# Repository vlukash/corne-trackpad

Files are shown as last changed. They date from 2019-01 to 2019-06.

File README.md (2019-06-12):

# Trackpad in a Keycap for Corne/CrKbd Keyboard

This is a Trackpad add-on for the [Corne](https://github.com/foostan/crkbd) keyboard.

This add-on consists of two main parts:
- an adapter PCB that goes between Elite-C and the main keyboard
- a connector PCB that links trackpad with the adapter

There are two different options available for the Trackpad sensor mount (connector PCB)
- on the 'H' button keycap via flex cable (Connector V1)
- no-flex mount directly on the connector PCB (Connector V2)

Both options compatible with the main adapter PCB, see photos below.

Schematics and PCB design included in this repository.
[Trackpad.c](https://github.com/vlukash/qmk_firmware/blob/master/keyboards/crkbd/keymaps/vlukash_trackpad_right/trackpad.c) reads the trackpad data and sends it to QMK.

Please find more information in my [blogpost](https://vlukash.com/2019/01/15/trackpad-in-keycap-corne-crkbd-keyboard/).

## Video
Turn on the subtitles option :)

https://www.youtube.com/watch?v=eY_9cieYMEQ

## Build Guide
https://github.com/vlukash/corne-trackpad/blob/master/build-guide.md

## Firmware
Corne keyboard uses [QMK](https://github.com/qmk/qmk_firmware) - an open-source keyboard firmware project.  
Please use [QMK guide](https://docs.qmk.fm/#/newbs_getting_started) to setup your local environment.  

The Trackpad add-on uses right-master configuration, and USB cable connects to the right keyboard with the trackpad.

Because of the adapter PCB, left and right keyboards have to be flashed with different firmware.

To build and flash the right keyboard (with the trackpad):
```
make crkbd:vlukash_trackpad_right:dfu
```
And the left part
```
make crkbd:vlukash_trackpad_left:dfu
```

[Here is a PR](https://github.com/qmk/qmk_firmware/pull/5925) that could be used as an example for creating your own Corne keymaps with the Trackpad add-on support.

## Photos
Trackpad sensor mounted directly on the connector PCB (Connector V2):
Corne with no-flex trackpad
Trackpad sensor mounted on 'H' button keycap via flex cable (Connector V1):
Corne with trackpad

All parts

Adapter

Adapter

Adapter

Connector

Connector

Connector

Button

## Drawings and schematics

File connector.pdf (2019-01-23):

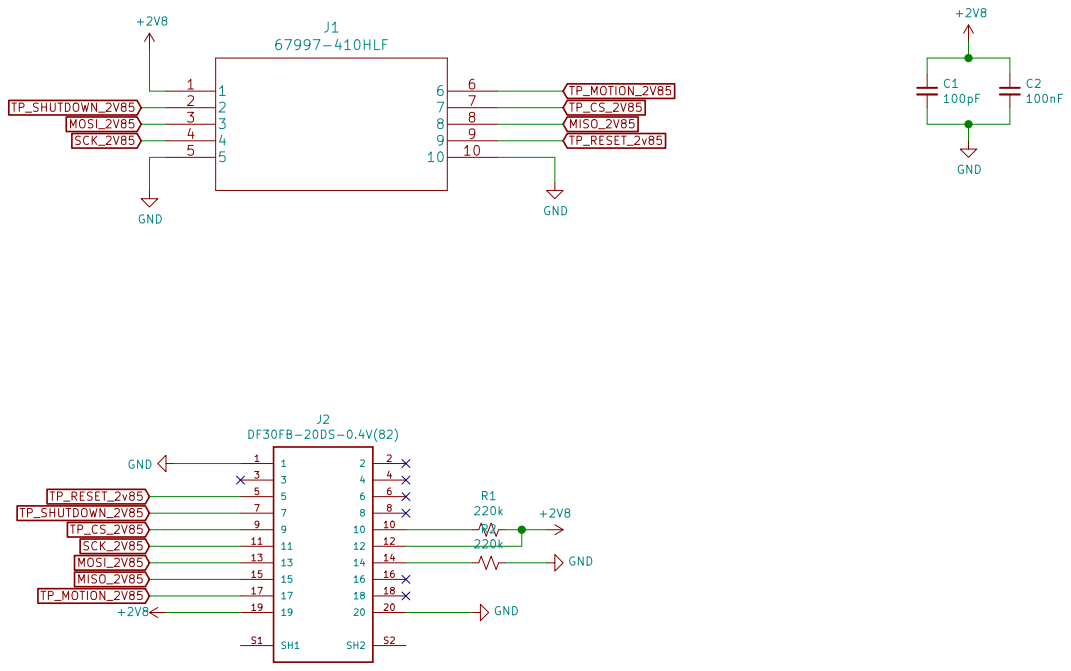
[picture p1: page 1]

File: trackpad_conn.sch Sheet: / vlukash Connector for the BlackBerry 8520 trackpad

Id: 1/1 Title: Trackpad connector

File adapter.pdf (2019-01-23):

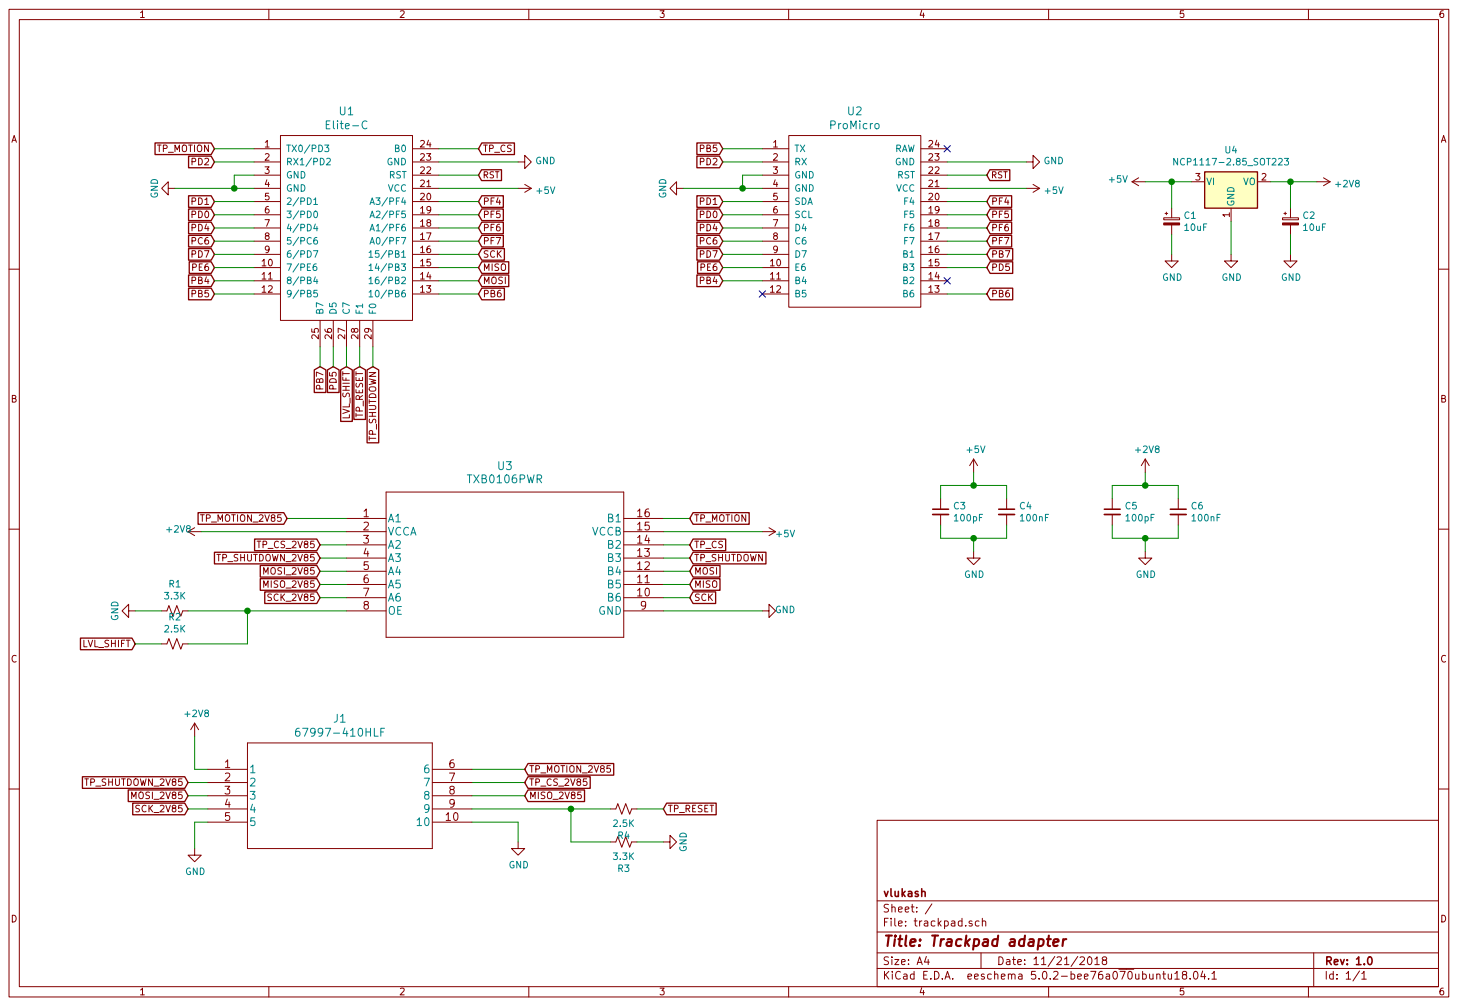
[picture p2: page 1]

File: trackpad.sch Sheet: / vlukash

Id: 1/1 Title: Trackpad adapter

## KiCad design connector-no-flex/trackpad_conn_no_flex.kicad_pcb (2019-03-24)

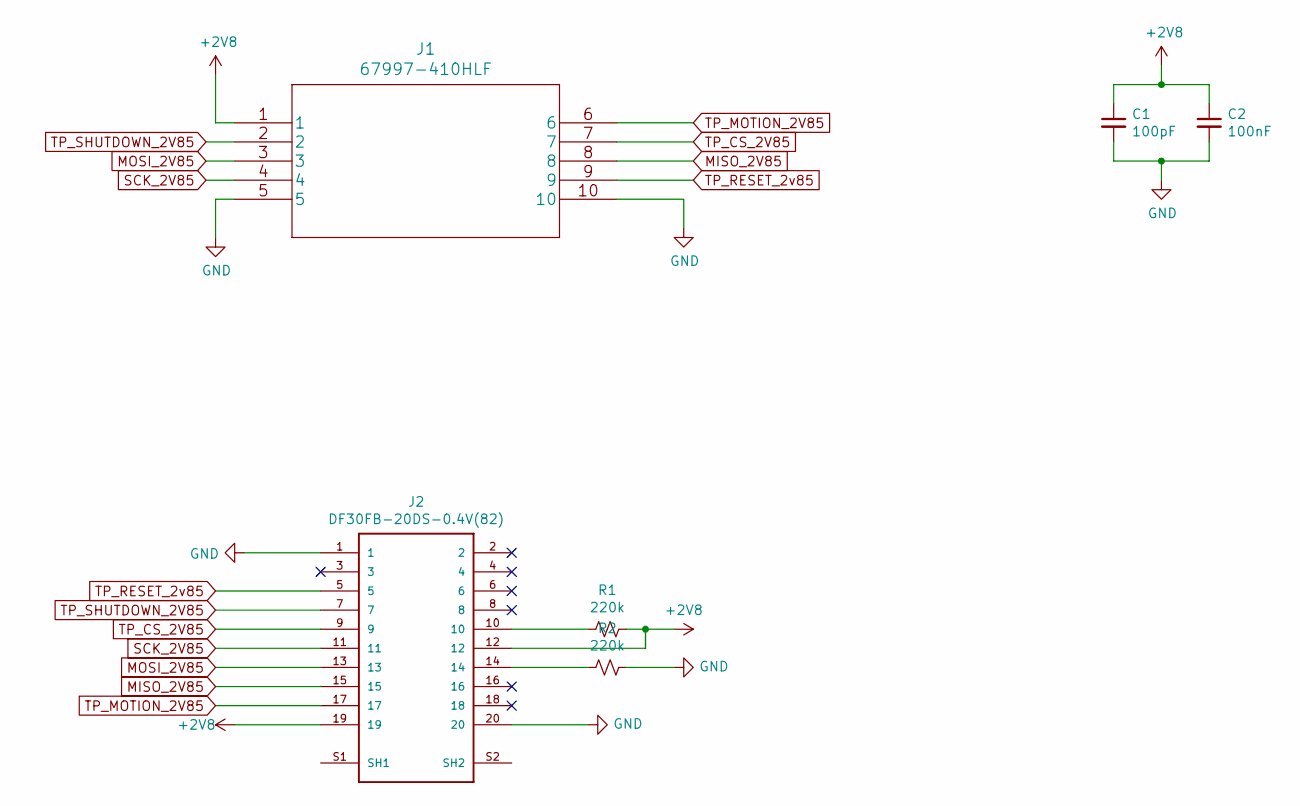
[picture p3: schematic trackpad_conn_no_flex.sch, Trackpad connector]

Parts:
C1: 100pF; C_0805_2012Metric
C2: 100nF; C_0805_2012Metric
J1: 67997-410HLF
J2: DF30FB-20DS-0.4V(82); HIROSE_DF30FB-20DS-0.4V(82)
R1, R2: 220k; R_0805_2012Metric

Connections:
+2V8: C1.1, C2.1, J1.1, J2.12, J2.19, R1.1
GND: C1.2, C2.2, J1.5, J1.10, J2.1, J2.20, R2.1
MISO_2V85: J1.8, J2.15
MOSI_2V85: J1.3, J2.13
unnamed: J2.10, R1.2
unnamed: J2.14, R2.2
SCK_2V85: J1.4, J2.11
TP_CS_2V85: J1.7, J2.9
TP_MOTION_2V85: J1.6, J2.17
TP_RESET_2v85: J1.9, J2.5
TP_SHUTDOWN_2V85: J1.2, J2.7

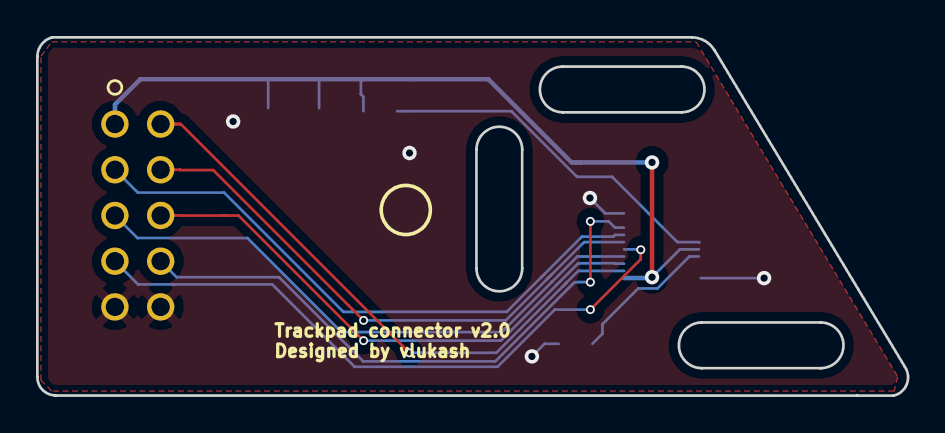
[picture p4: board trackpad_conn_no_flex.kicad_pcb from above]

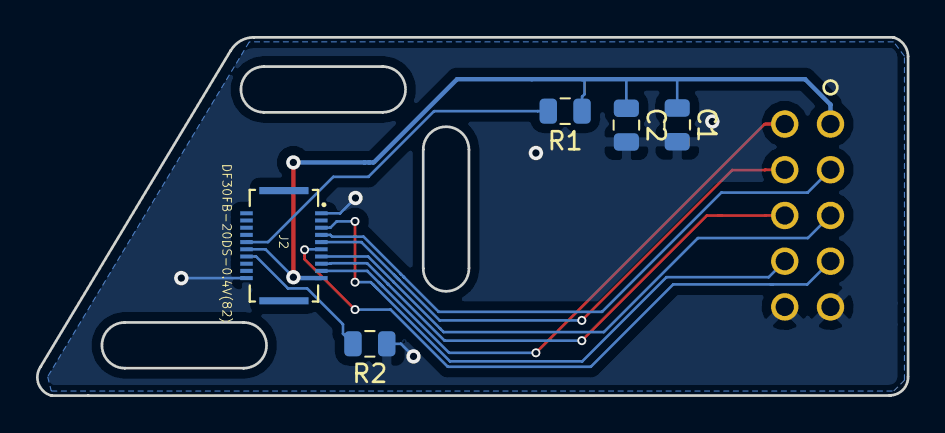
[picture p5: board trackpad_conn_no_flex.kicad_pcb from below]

Board: 2 copper layers, 48.4 x 19.9 mm, 6 parts (5 on the bottom side), 11 nets.

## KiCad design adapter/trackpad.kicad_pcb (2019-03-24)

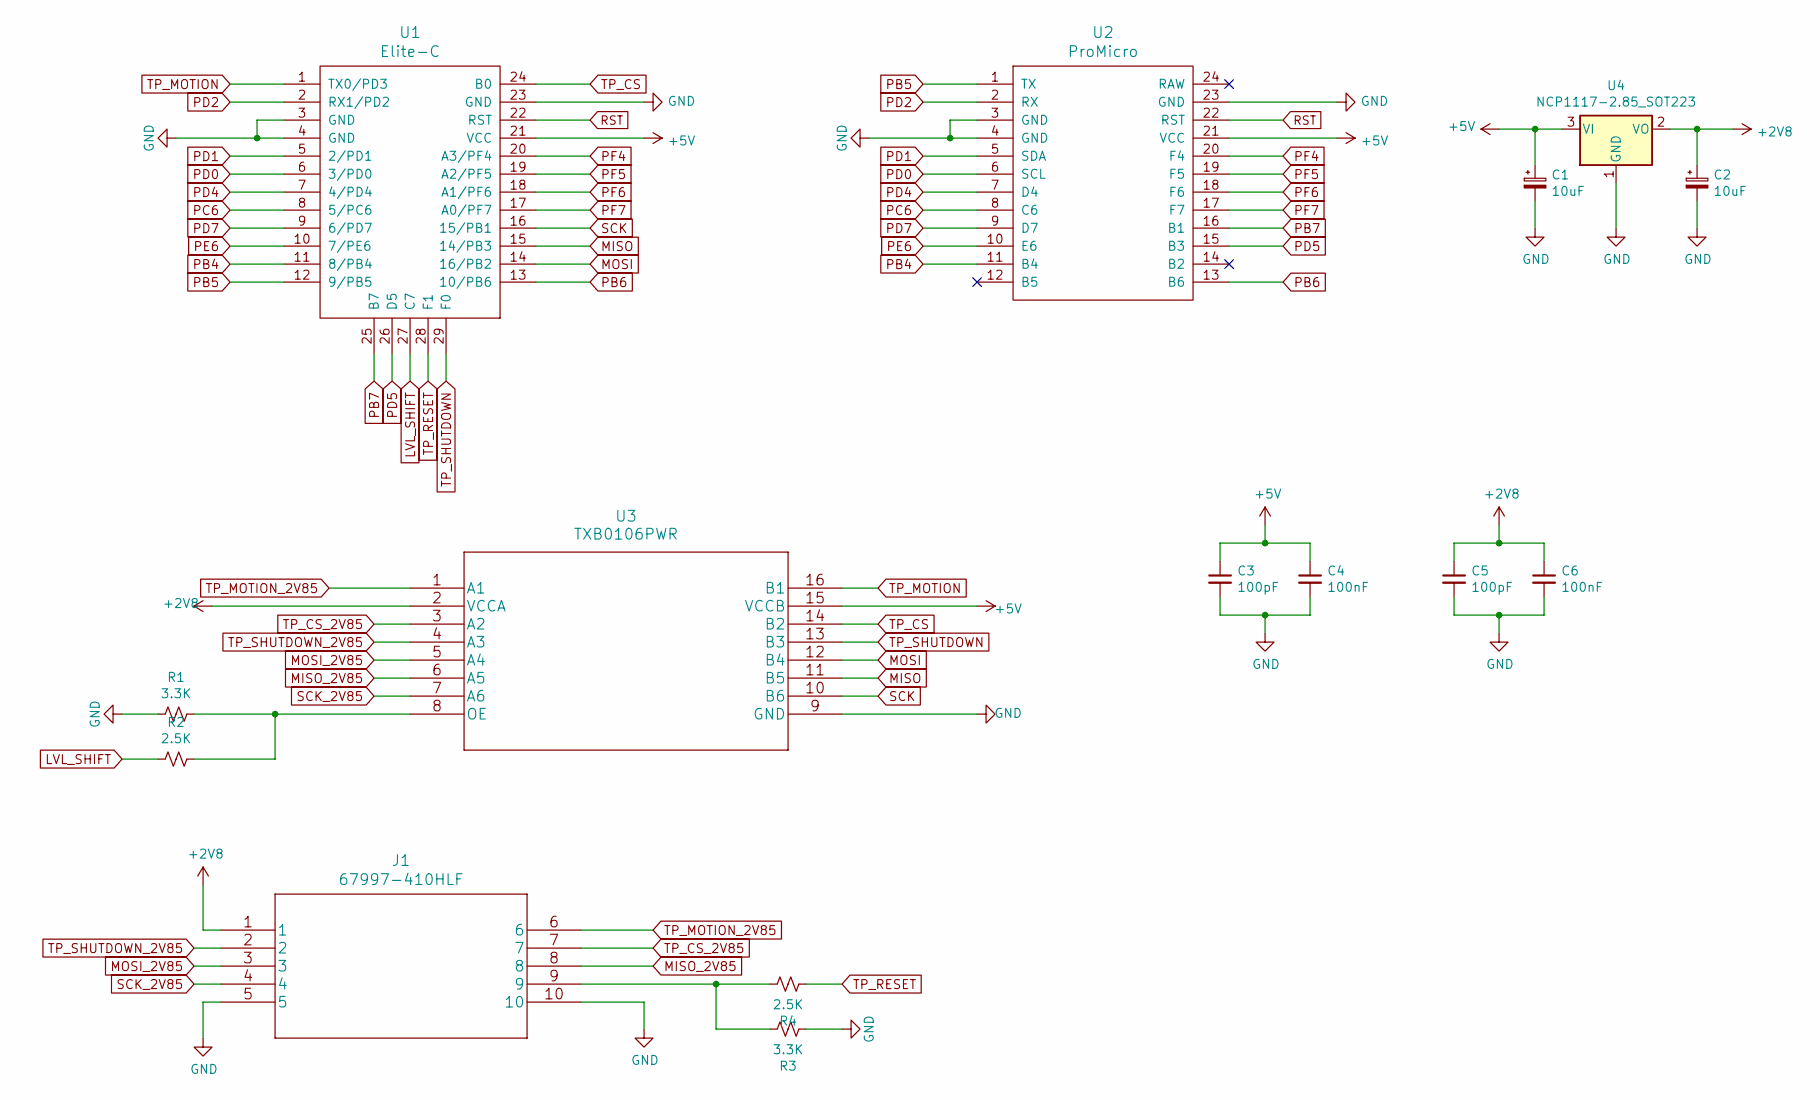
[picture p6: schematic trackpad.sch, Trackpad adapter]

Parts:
C1, C2: 10uF; CP_EIA-6032-15_Kemet-U
C3, C5: 100pF; C_0805_2012Metric
C4, C6: 100nF; C_0805_2012Metric
J1: 67997-410HLF
R1, R3: 3.3K; R_0805_2012Metric
R2, R4: 2.5K; R_0805_2012Metric
U1: Elite-C
U2: ProMicro; ArduinoProMicro
U3: TXB0106PWR
U4: NCP1117-2.85_SOT223; SOT-223-3_TabPin2

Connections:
+2V8: C2.1, C5.1, C6.1, J1.1, U3.2 (VCCA), U4.2 (VO)
+5V: C1.1, C3.1, C4.1, U1.21 (VCC), U2.21 (VCC), U3.15 (VCCB), U4.3 (VI)
GND: C1.2, C2.2, C3.2, C4.2, C5.2, C6.2, J1.5, J1.10, R1.2, R3.2, U1.3 (GND), U1.4 (GND), U1.23 (GND), U2.3 (GND), U2.4 (GND), U2.23 (GND), U3.9 (GND), U4.1 (GND)
LVL_SHIFT: R2.2, U1.27 (C7)
MISO: U1.15 (14/PB3), U3.11 (B5)
MISO_2V85: J1.8, U3.6 (A5)
MOSI: U1.14 (16/PB2), U3.12 (B4)
MOSI_2V85: J1.3, U3.5 (A4)
unnamed: J1.9, R3.1, R4.1
unnamed: R1.1, R2.1, U3.8 (OE)
PB4: U1.11 (8/PB4), U2.11 (B4)
PB5: U1.12 (9/PB5), U2.1 (TX)
PB6: U1.13 (10/PB6), U2.13 (B6)
PB7: U1.25 (B7), U2.16 (B1)
PC6: U1.8 (5/PC6), U2.8 (C6)
PD0: U1.6 (3/PD0), U2.6 (SCL)
PD1: U1.5 (2/PD1), U2.5 (SDA)
PD2: U1.2 (RX1/PD2), U2.2 (RX)
PD4: U1.7 (4/PD4), U2.7 (D4)
PD5: U1.26 (D5), U2.15 (B3)
PD7: U1.9 (6/PD7), U2.9 (D7)
PE6: U1.10 (7/PE6), U2.10 (E6)
PF4: U1.20 (A3/PF4), U2.20 (F4)
PF5: U1.19 (A2/PF5), U2.19 (F5)
PF6: U1.18 (A1/PF6), U2.18 (F6)
PF7: U1.17 (A0/PF7), U2.17 (F7)
RST: U1.22 (RST), U2.22 (RST)
SCK: U1.16 (15/PB1), U3.10 (B6)
SCK_2V85: J1.4, U3.7 (A6)
TP_CS: U1.24 (B0), U3.14 (B2)
TP_CS_2V85: J1.7, U3.3 (A2)
TP_MOTION: U1.1 (TX0/PD3), U3.16 (B1)
TP_MOTION_2V85: J1.6, U3.1 (A1)
TP_RESET: R4.2, U1.28 (F1)
TP_SHUTDOWN: U1.29 (F0), U3.13 (B3)
TP_SHUTDOWN_2V85: J1.2, U3.4 (A3)

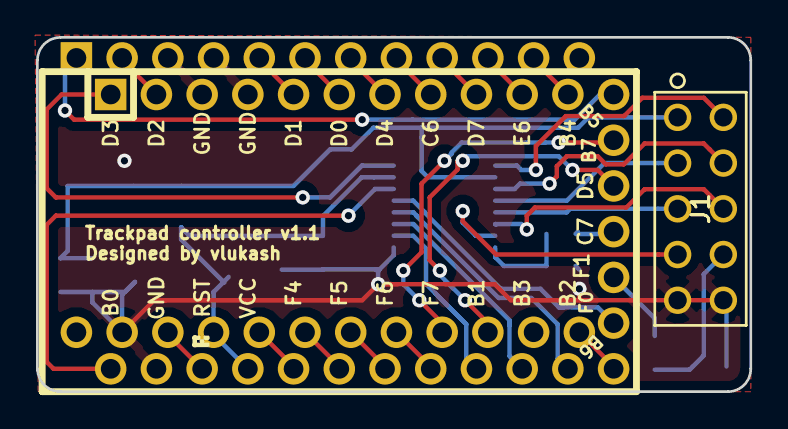
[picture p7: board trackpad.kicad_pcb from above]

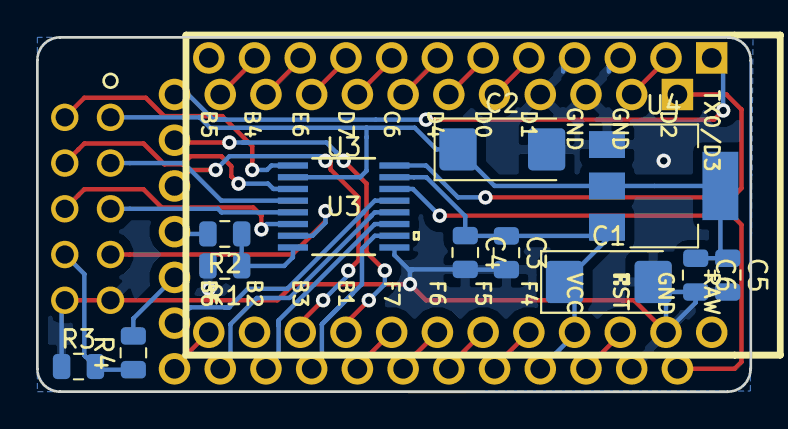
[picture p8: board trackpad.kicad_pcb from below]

Board: 2 copper layers, 39.6 x 19.7 mm, 15 parts (14 on the bottom side), 36 nets.

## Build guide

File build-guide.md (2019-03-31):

# Build Guide

A trackpad build guide for the Corne keyboard.

## Parts
| Name | Number | Notes | 
|:-|:-|:-|
| Adapter PCB | 1 |
| Connector PCB | 1 | v1 or v2, based on the sensor mount type
| [Elite-C](https://keeb.io/products/elite-c-usb-c-pro-micro-replacement-arduino-compatible-atmega32u4) | 1 |
| [BlackBerry 8520 trackpad](https://www.ebay.com/i/281933297131) | 1 |
| [TXB0106PWR](https://www.digikey.com/product-detail/en/texas-instruments/TXB0106PWR/296-23759-1-ND/1951146) | 1 | Bidirectional level shifter 5V <-> 2.85V
| [DF30FB-20DS-0.4V](https://www.digikey.com/product-detail/en/hirose-electric-co-ltd/DF30FB-20DS-0.4V(82)/H11591CT-ND/1949227) | 1 | SMD connector for BB8520 
| [LT1117CST-2.85](https://www.digikey.com/product-detail/en/linear-technology/LT1117CST-2.85%23PBF/LT1117CST-2.85%23PBF-ND/890802) | 1 | 2.85V DC Regulator
| [Mill-Max sockets](https://www.digikey.com/product-detail/en/mill-max-manufacturing-corp/315-43-164-41-003000/ED4764-64-ND/1212143) | 1 |
| [Mill-Max pins](https://www.digikey.com/product-detail/en/mill-max-manufacturing-corp/3320-0-00-15-00-00-03-0/ED1134-ND/4147392) | 50 |
| [10 Position Cable Socket](https://www.digikey.com/product-detail/en/samtec-inc/IDSD-05-D-20.00-T/SAM8929-ND/3679935) | 1 | Or any compatible
| [Connector header 10POS 2.54MM](https://www.digikey.com/product-detail/en/amphenol-icc-fci/67997-410HLF/609-3243-ND/1878475) | 1 |
| [Capacitor 10uF](https://www.digikey.com/product-detail/en/kemet/T491C106K010AT/399-3731-1-ND/819056) | 2 |
| [Capacitor 100pF](https://www.digikey.com/product-detail/en/samsung-electro-mechanics/CL21C101JC61PNC/1276-2569-1-ND/3890655) | 3 |
| [Capacitor 0.1uF](https://www.digikey.com/product-detail/en/kemet/C0805X104K4RACTU/399-5331-1-ND/1842310) | 3 |
| [Resistor 2.5k](https://www.digikey.com/product-detail/en/vishay-thin-film/PTN0805E2501BST1/764-1508-1-ND/7103292) | 2 |
| [Resistor 3.3k](https://www.digikey.com/product-detail/en/panasonic-electronic-components/ERJ-PB6B3301V/P20651CT-ND/6214906) | 2 |
| [Resistor 220k](https://www.digikey.com/product-detail/en/panasonic-electronic-components/ERA-6AEB224V/P220KDACT-ND/1466003) | 2 |
| Spacer M2 10mm | 4 |

List

## Options
There are two options for the BlackBerry 8520 sensor mount:
- v1 connector PCB - with flex cable. The sensor is mounted directly on the 'H' keycap.
- v2 connector PCB - no flex mount. The sensor is mounted directly on the connector PCB.

This build guide shows the v2 option, but v1 is very similar from the build perspective.

## Build Steps

#### 1. TXB0106PWR


#### 2. 2.85V DC Regulator


#### 3. Capacitors 10uF


#### 4. Capacitors 0.1uF


#### 5. Capacitors 100pF


#### 6. Resistors 2.5k


#### 7. Resistors 3.3k


#### 8. Mill-Max sockets



#### 9. Solder Mill-Max pins to Elite-C




#### 10. Connector header 10POS


#### 11. SMD connector for BB8520, reqires small soldering tip


#### 12. 0.1uF and 100pF capacitors 


#### 13. Resistors 220k


#### 14. Prepare and solder connector cable.





#### 15. Connect and glue Trackpad sensor to the PCB




#### 16. Solder Mill-Max pins to the Adapter PCB


#### 17. Assemble the module


#### 18. Connect to Corne keyboard



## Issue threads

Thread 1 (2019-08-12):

[question] have tried the other trackpad models without connector?

v01d, 2019-08-12:
I see several trackpad models available for similar price, from different BlackBerry versions. Some of these have simple exposed pads on the flexible PCB connector, which seems easier to solder against a PCB, not requiring the tiny hirose connector you used. Did you tried using one of these? I would like to buy and try one but I could not find a pinout for these.
How did you found the pinout for your model?

Thank you!!

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

vlukash, 2019-08-29:
Hi,

I considered only two trackpad models for this project - BB8520 and BB9900, as I wasn't able to find any documentation on other BB trackpads. I believe ([based on this link](https://forum.arduino.cc/index.php?topic=302036.msg2143236#msg2143236)) BB9900 uses I2C and 9520 uses SPI [(some details on Arduino forum](https://forum.arduino.cc/index.php?topic=61637.msg1754304#msg1754304)).
Also, I found a really good source [here](https://docs.greycat.co/trackpad.html#intro) for the 8520.

I'd be interested in any information on other BB modules. Please share if you get any updates!

Thanks!

v01d, 2019-08-29:
I actually bough 9800 and 9900 sensors and made the 9800 work: https://hackaday.io/project/167075-thumbmouse
You are correct, both of these have same pinout and work over I2C.

I'm now struggling to find appropriate connectors. I believe I found one from I-Pex for the 9900 but none for the 9800.

vlukash, 2019-09-03:
Glad to hear you've made the 9800 work!
Good luck with the project!

tg-x, 2020-03-17:
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

@v01d do you have a link / part nr to the connector from i-pex?

looks like 9800/9900 is easier to find on ebay and would be great to be able to make it work with crkbd, 8250 seems more rare

v01d, 2020-05-15:
Sorry for the late response, the part number I manage to find (can't verify if it is indeed compatible) is: 20599-013E-01

v01d, 2020-05-15:
Actually, i will probably order soon a few connectors I've found on Mouser for the 9900 (0.3mm pitch): https://ar.mouser.com/ProductDetail/649-1061122131120HLF
I will use it to make a breakout board for it (including require regulators and level translators)

mryndzionek, 2020-10-27:
Hello @v01d  and @vlukash. I would like to use 9800 trackpad in my project, but the schematics/pinouts on Arduino forum don't seem to be available anymore. I have two questions:

1.  what is `VSYS` pin ?
2.  what is the register/command that switches to 1000cpi ?

v01d, 2020-10-27:
After some testing, I don't recommend the 9900/9800 series of trackpads since they required connector is not available. I tried one that looked similar but ended up having to modify it to fit. I think the trackpads which have the square mezzanine connector are much better and there are parts available. The ones with 20 pins are SPI and only require 2.8v supply. The 14 pin ones are I2C and require both 2.8v and 1.8v. I made a breakout for the I2C variants but have not tested it yet.

v01d, 2020-10-27:
By the way, you may find my [thumbmouse](https://hackaday.io/project/167075-thumbmouse) project of interest, as it involves blackberry trackpads.

mryndzionek, 2020-10-27:
Yes, I've seen your project @v01d. Actually your log is the best place that summarizes available information regarding the trackpads. I only have the 9800 available and I won't be using the connector for now. The only info I'm missing is:

 1. what is VSYS pin ?
 2. what is the register/command that switches to 1000cpi ?

Would you be able to answer those questions?

v01d, 2020-10-27:
1. That pin supposedly is related to a LED which I'm not sure is supposed to be powered from that pin or that you should power it yourself. I've left it disconnected, it is not important. Note the description here: https://hackaday.io/project/167075/logs (9800 and 9900 have actually the same pinout)
2. I don't remember know which datasheet I've used for the 9900 but I believe all trackpads behave as a ADNS3530 (at least that is true for the 8520). So that would be register 0x11, bit 7 set to 1.

[ADNS-3530.pdf](https://github.com/vlukash/corne-trackpad/files/5446264/ADNS-3530.pdf)

A driver for the 8520 for NuttX is here: https://gitlab.com/nuttx_projects/bb_trackpad
It may be useful to understand how registers are used.

shrekale, 2022-07-23:
Hey @vlukash I had an old BB Q20 from which I harvested the trackpad. Unfortunately, I lost the connector socket in the trash. Are these connectors available outside? I really don’t want to shuffle through my trashcan to find it 🤢

shrekale, 2022-07-23:
No worries, found the connector. All I need is to design the breakout and order it. I am planning on double stacking it on the back of Nice!Nano. So, Nice!nano will have pins on one side and socket on the back of it, and the breakout will be exactly of that size which will get socketed on top. Lets see how that works, it's my first ever project that involves designing a PCB.

stolen, 2022-08-02:
Hi guys. I'm late to the party, but maybe some current/future enthusiasts will find ths useful.

  * The chip is ADBS-A320, the datasheet is available online
  * 3.3v is OK, no 2.8v regulator needed
  * It has burst mode (it needs to be configured explicitly) and finger detection
  * Hirose FH35C-17S seems to be OK for 9900 (I don't have a board for it yet)

I've gathered some info in my repo: https://github.com/stolen/blackberry_trackpad

Closed 2019-12-28.

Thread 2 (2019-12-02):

Cheaper DC Regulator

BenRoe, 2019-12-02:
Hi,
i looking for a cheaper DC Regulator and found this [one here](https://www.digikey.com/product-detail/en/texas-instruments/TPS793285DBVR/296-12157-1-ND/411993).
I never used a voltage regulator, so i have to study both data-sheets.
If you have time, i appreciate your help.

Already build a trackpad board. Works great. Will remove the connector header and solder the cable direct to the board, to reduce the height.

vlukash, 2019-12-28:
Hi,
Thanks for finding a cheaper regulator, the TPS793285DBVR should work just fine! It has a bit lower max output current, but I'm sure 200ma is more than enough to power BB sensor!

Happy to hear you've built a trackpad!

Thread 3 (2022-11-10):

Using the adapter for PMW33XX

hochshi, 2022-11-10:
Hi,

Great work, it's nice to see such a detailed explanation as well.

I'm really new to this, but as far as I managed to figure out, the adapter board you've created would be compatible with PMW33XX, ADNS-9800
(https://www.tindie.com/products/jkicklighter/pmw3360-motion-sensor/, https://www.tindie.com/products/jkicklighter/pmw3389-motion-sensor/, https://www.tindie.com/products/jkicklighter/adns-9800-laser-motion-sensor/) right out of the box without using the connector. Am I correct?

Does this means I could add a trackball without printing a completely custom PCB? That would be great.

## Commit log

2019-01-17 Add trackpad schematics and PCB designs.
    [trackpad.kicad_pcb, trackpad.sch, trackpad_conn.kicad_pcb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]
2019-01-23 Add schematics in PDF format
2019-03-24 Update PCB length so it doesn't block USB-C connector.
    [trackpad.kicad_pcb]
2019-03-24 Add v2.0 connector. This version designed for direct trackpad mount on the PCB, instead of the keycap.
    [trackpad_conn_no_flex.kicad_pcb, trackpad_conn_no_flex.sch]

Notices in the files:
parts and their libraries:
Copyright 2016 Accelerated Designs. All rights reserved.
